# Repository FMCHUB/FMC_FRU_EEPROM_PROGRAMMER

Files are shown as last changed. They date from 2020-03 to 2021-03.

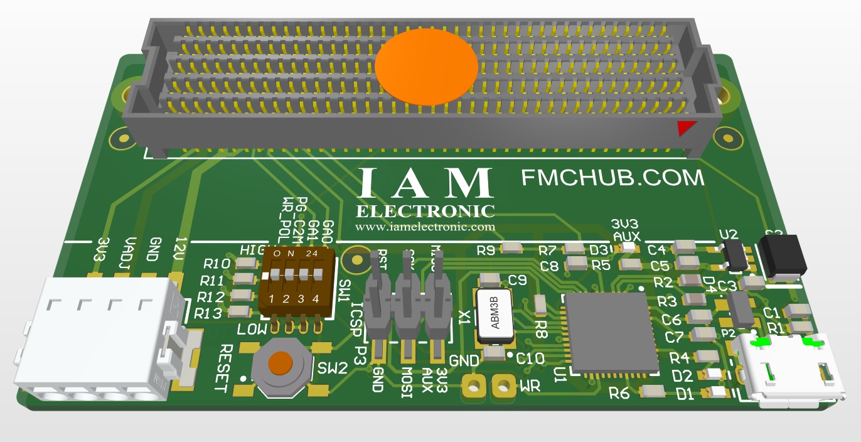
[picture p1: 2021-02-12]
PCB_ALTIUM/3d_pcb_view_revB.jpg

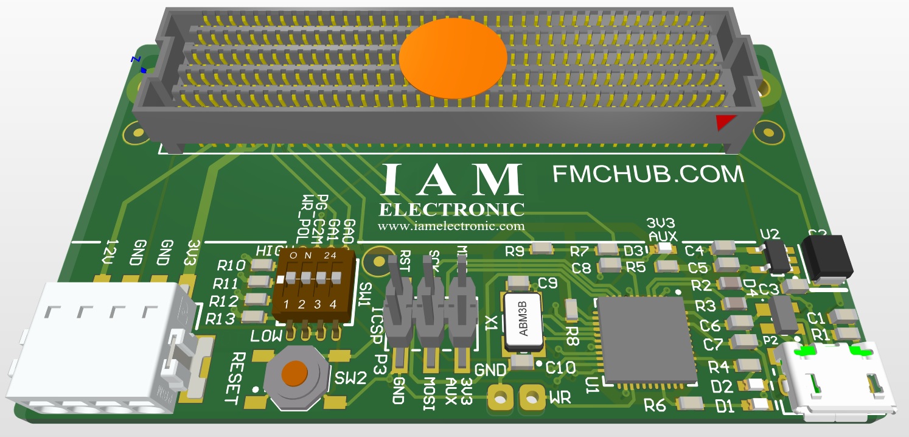
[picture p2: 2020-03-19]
PCB_ALTIUM/3d_pcb_view.jpg

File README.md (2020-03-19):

# FMC_FRU_EEPROM_PROGRAMMER
FRU EEPROM PROGRAMMER FOR FPGA MEZZANINE CARDS (FMC)

1. ./DRIVER

   contains all neccessary driver files for the FMC FRU EEPROM Programmer

2. ./FIRMWARE_ATMEL

   contains the firmware (Atmel Studio project) for the ATMEGA32U4 microcontroller device

3. ./PCB_ALTIUM

   contains the PCB files (Altium designer project) for the FMC FRU EEPROM Programmer

4. ./SOFTWARE_CMD_TOOLS

   contains the command line tools for easy use of FMC FRU EEPROM Programmer

(C) 2020

FMCHUB.COM

IAMELECTRONIC.COM

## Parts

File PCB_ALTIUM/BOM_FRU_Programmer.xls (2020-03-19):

Designator | Description | Manufacturer | Part | Quantity
C1, C3, C4, C7 | CAP 100nF, 0603 (1608 Metric) | KEMET | C0603C104M4RAC7411 | 4
C2 | Standard Tantalum, 22 uF, +/- 10%, 16 V, -55 to 125 degC, 2-Pin SMD (1210), RoHS, Tape and Reel | AVX | TAJB226K016RNJ | 1
C5, C6, C8 | CAP 2.2uF, 0603 (1608 Metric) | KEMET | C0603C225K4PACTU | 3
C9, C10 | CAP 22pF, 0603 (1608 Metric) | Yageo | CC0603JRNPO9BN220 | 2
D1 | LED 0603, 2V, Yellow | Wuerth Elektronik | 150060YS75000 | 1
D2 | LED 0603, 2V, Green | Wuerth Elektronik | 150060VS75000 | 1
D3 | LED 0603, 2V, Red | Wuerth Elektronik | 150060RS75000 | 1
D4 | TVS Diode Array, 30 pF, 30 KV, -40 to 85 degC, 4-Pin SOT143, RoHS, Tape and Reel | Littelfuse | SP0503BAHTG | 1
P1 | CC-LPC-10, FMC Low-pin count connector, lead free, 160 I/Os, female, 10 mm mated stack height | Samtec | ASP-134603-01 | 1
P2 | Micro USB B Type Receptacle, -55 to 85 degC, 5-Pin SMD, RoHS, Tape and Reel | FCI | 10118193-0001LF | 1
P3 | .100" (2.54 mm) pitch 6 pin (dual row) header, 0.38" (9.65 mm) total height, SMT | Samtec | TSM-103-01-T-DV | 1
P4 | Phoenix Contact PTSM SMT connector | Phoenix Contact | 1814650 | 1
R1 | Resistor, 1 MOhm, 0603 (1608 Metric) | Yageo | RC0603JR-071ML | 1
R2, R3 | 22R 0.1W 5% 0603 (1608 Metric) SMD | Yageo | RC0603FR-0722RL | 2
R4, R5, R6 | Resistors, 220 Ohm, +/- 1%, 0603 (1608 Metric) | Yageo | RC0603FR-07220RL | 3
R7, R8, R9, R10, R11, R12, R13 | Resistor, 10 KOhm, 0603 (1608 Metric) | Walsin | WR06X1002FTL | 7
SW1 | 4 channel DIP switch | CTS Electronic Components | 218-4LPST | 1
SW2 | Switch, Tactile, SPST-NO, 50 mA, 12 V, 4-Pin SMD, RoHS, Tape and Reel | E-Switch | TL3342F160QG | 1
U1 | 8-bit AVR Microcontroller, 2.7-5.5V, 16MHz, 32KB Flash, 1KB EEPROM, 2.5KB SRAM, USB Controller, 44-pin QFN, Industrial Grade (-40°C to 85°C), Ext Osc | Microchip | ATMEGA32U4-MU | 1
U2 | Single Output Low Noise LDO, 150 mA, Fixed 3.3 V Output, 1.5% Tolerance, 2.2 to 16 V Input, Low IQ, 5-Pin SOT-23 (DBV), -40 to 125 degC, Green (RoHS & no Sb/Br), Tape and Reel | Texas Instruments | LP2985-33DBVR | 1
X1 | Ceramic Crystal, 8 MHz, +/- 10 ppm, -10 to 60 degC, 4-Pin SMD, RoHS, Tape and Reel | Abracon-LLC | ABM3B-8.000MHZ-10-1-U-T | 1

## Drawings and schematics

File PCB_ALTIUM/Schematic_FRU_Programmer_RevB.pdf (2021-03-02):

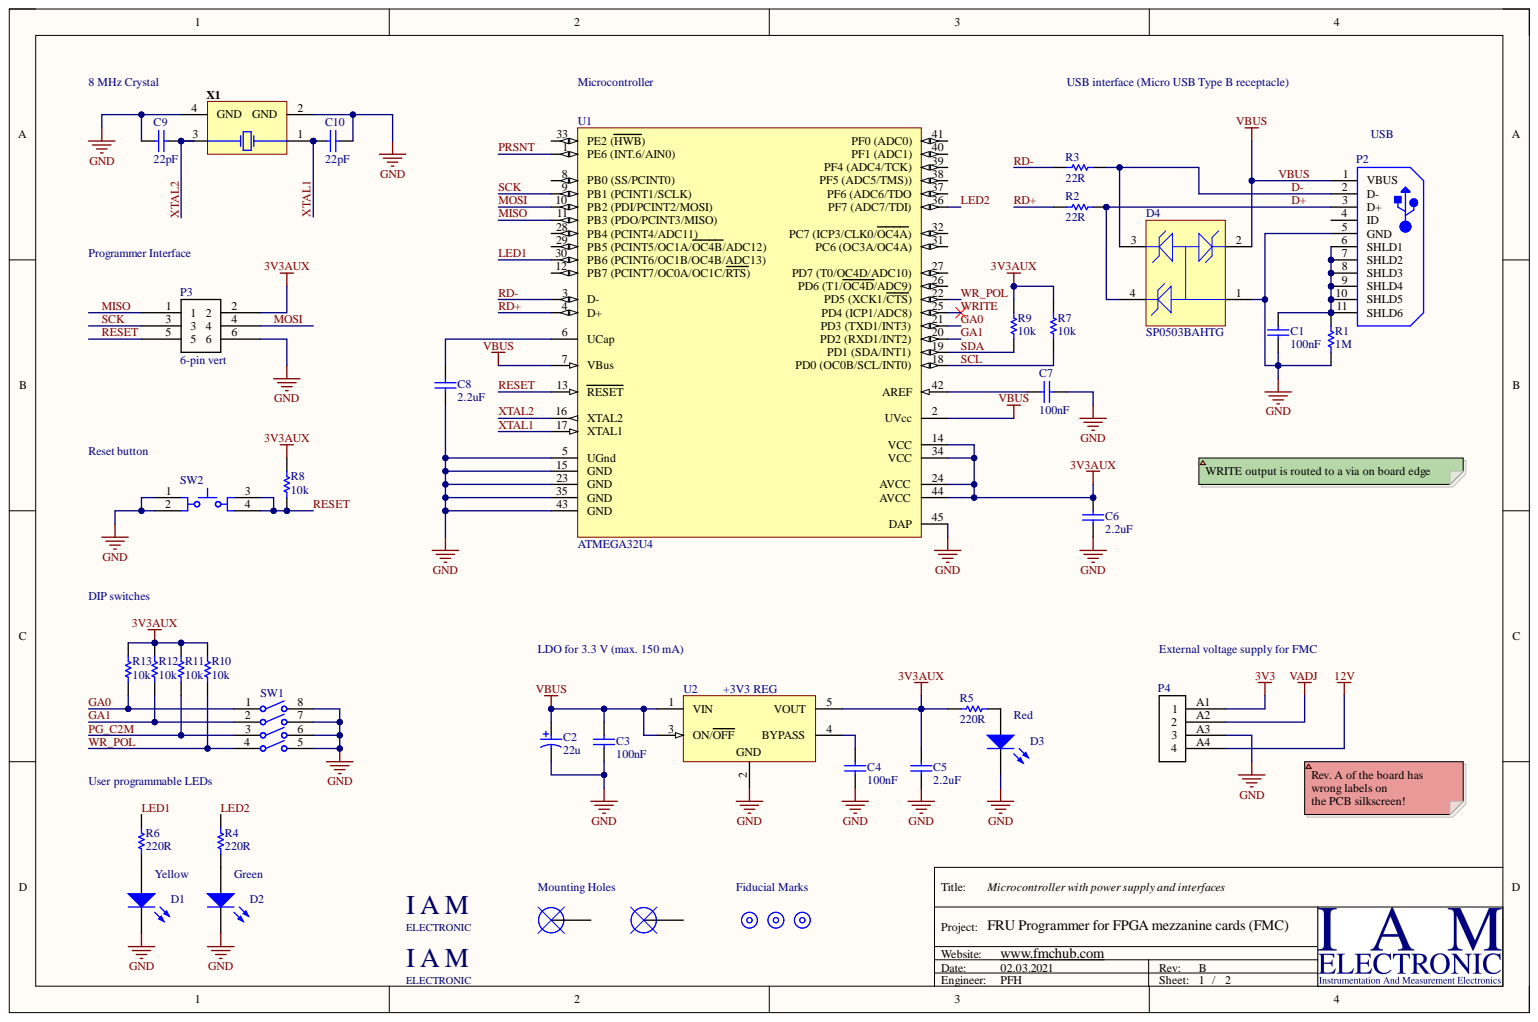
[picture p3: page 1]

USB interface (Micro USB Type B receptacle)

VBUS | VBus 7

SCL

WRITE output is routed to a via on board edge

LDO for 3.3 V (max. 150 mA)

External voltage supply for FMC

Rev. A of the board has
wrong labels on
the PCB silkscreen!

Microcontroller with power supply and interfaces

FRU Programmer for FPGA mezzanine cards (FMC)

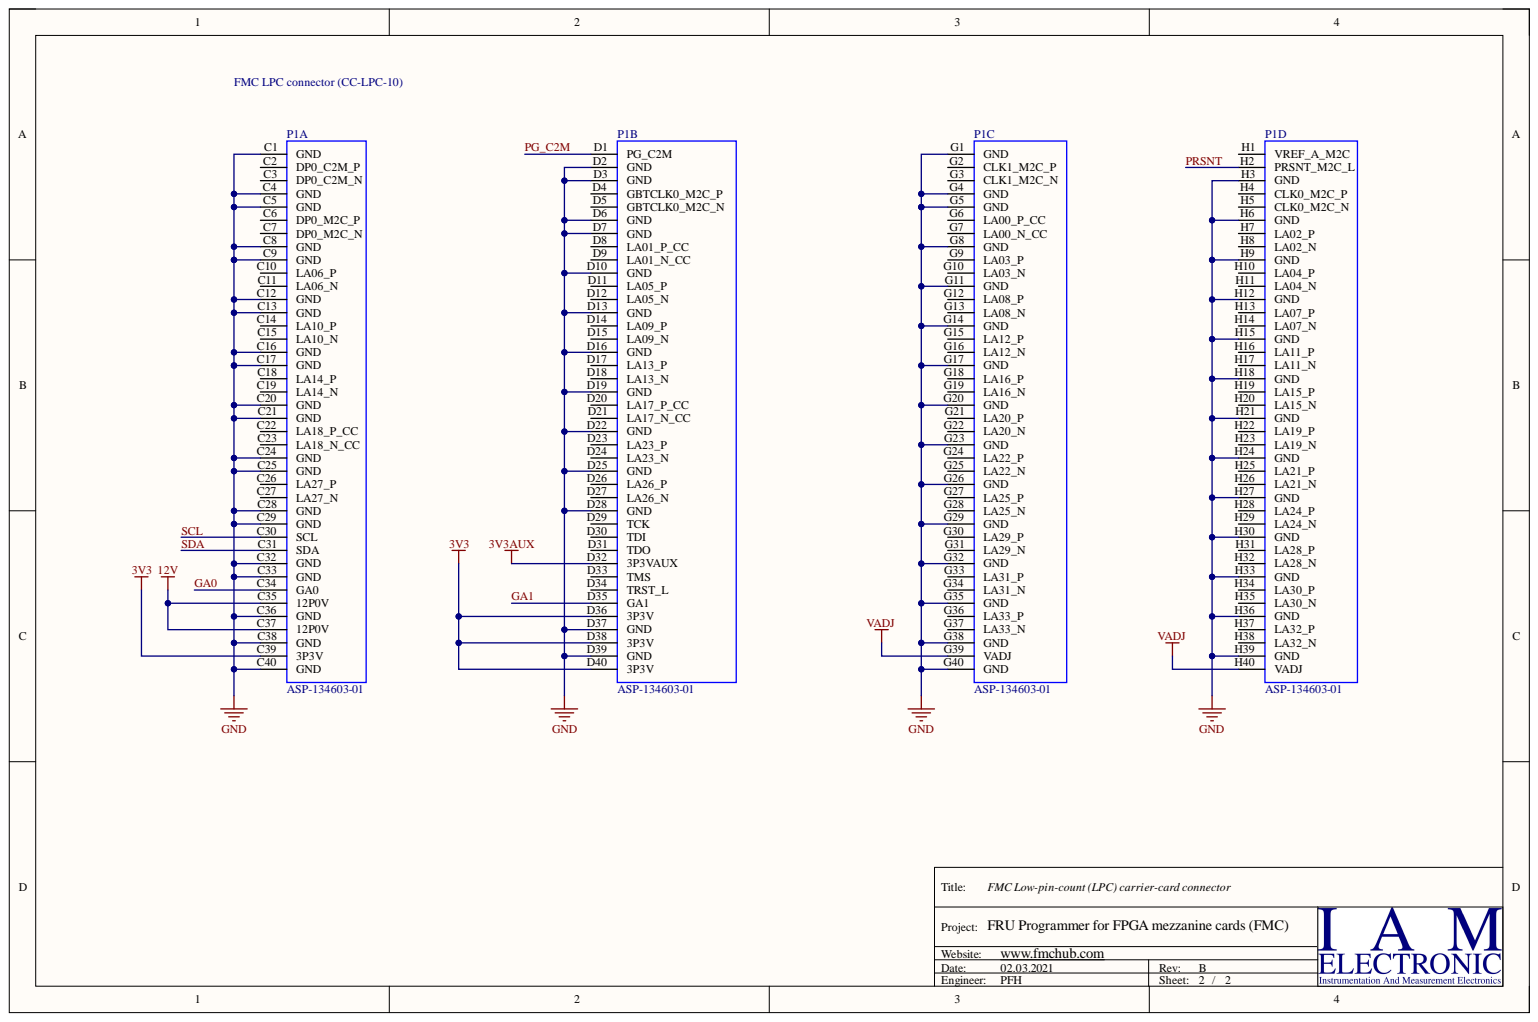
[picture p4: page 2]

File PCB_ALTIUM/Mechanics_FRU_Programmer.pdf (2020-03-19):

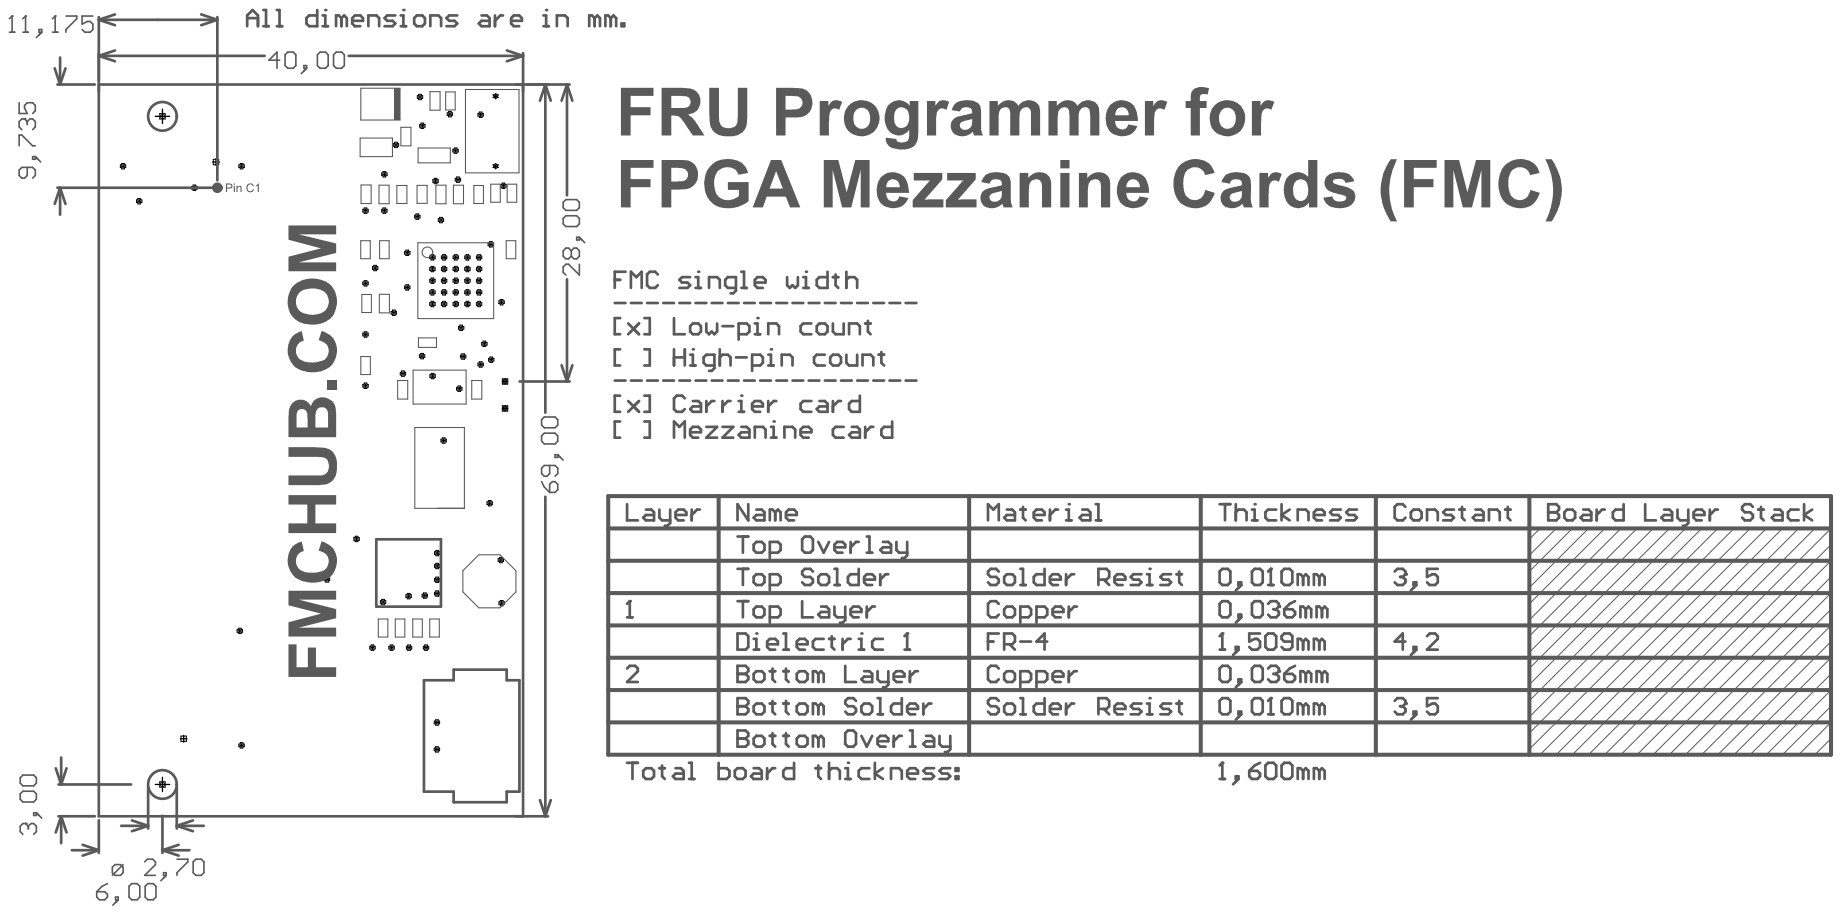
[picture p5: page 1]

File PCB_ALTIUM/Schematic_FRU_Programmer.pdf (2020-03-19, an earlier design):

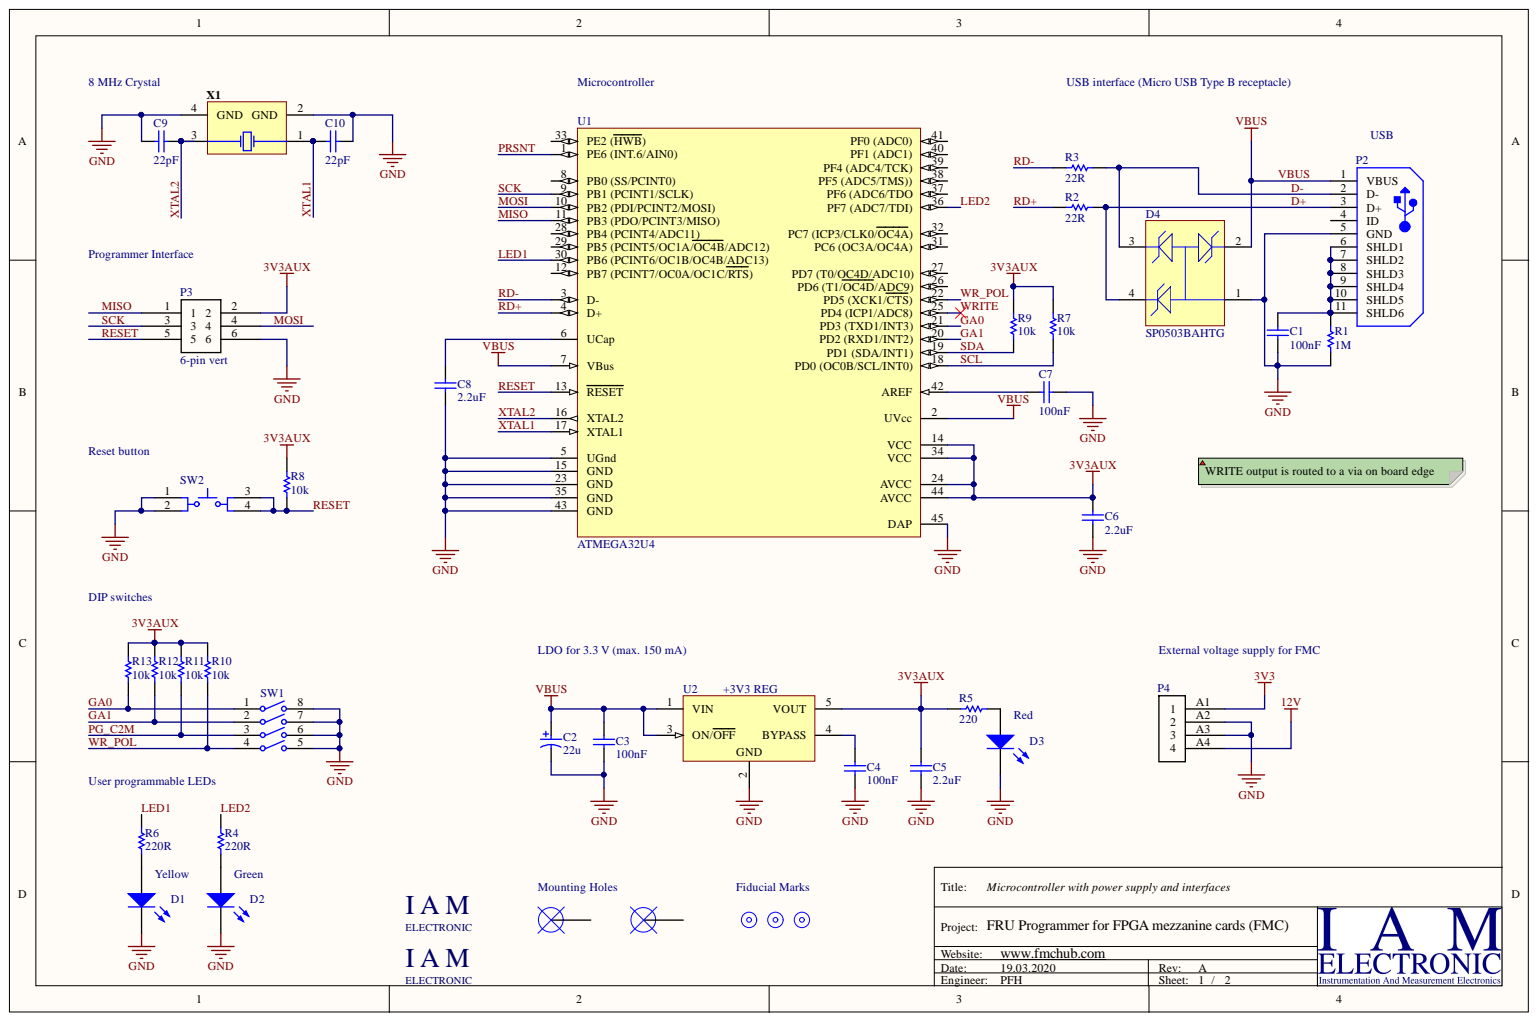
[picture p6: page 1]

USB interface (Micro USB Type B receptacle)

VBUS | VBus 7

SCL

WRITE output is routed to a via on board edge

LDO for 3.3 V (max. 150 mA)

External voltage supply for FMC

Microcontroller with power supply and interfaces

FRU Programmer for FPGA mezzanine cards (FMC)

Date: 19.03.2020 | Rev: A
Engineer: PFH | Sheet: 1 / 2

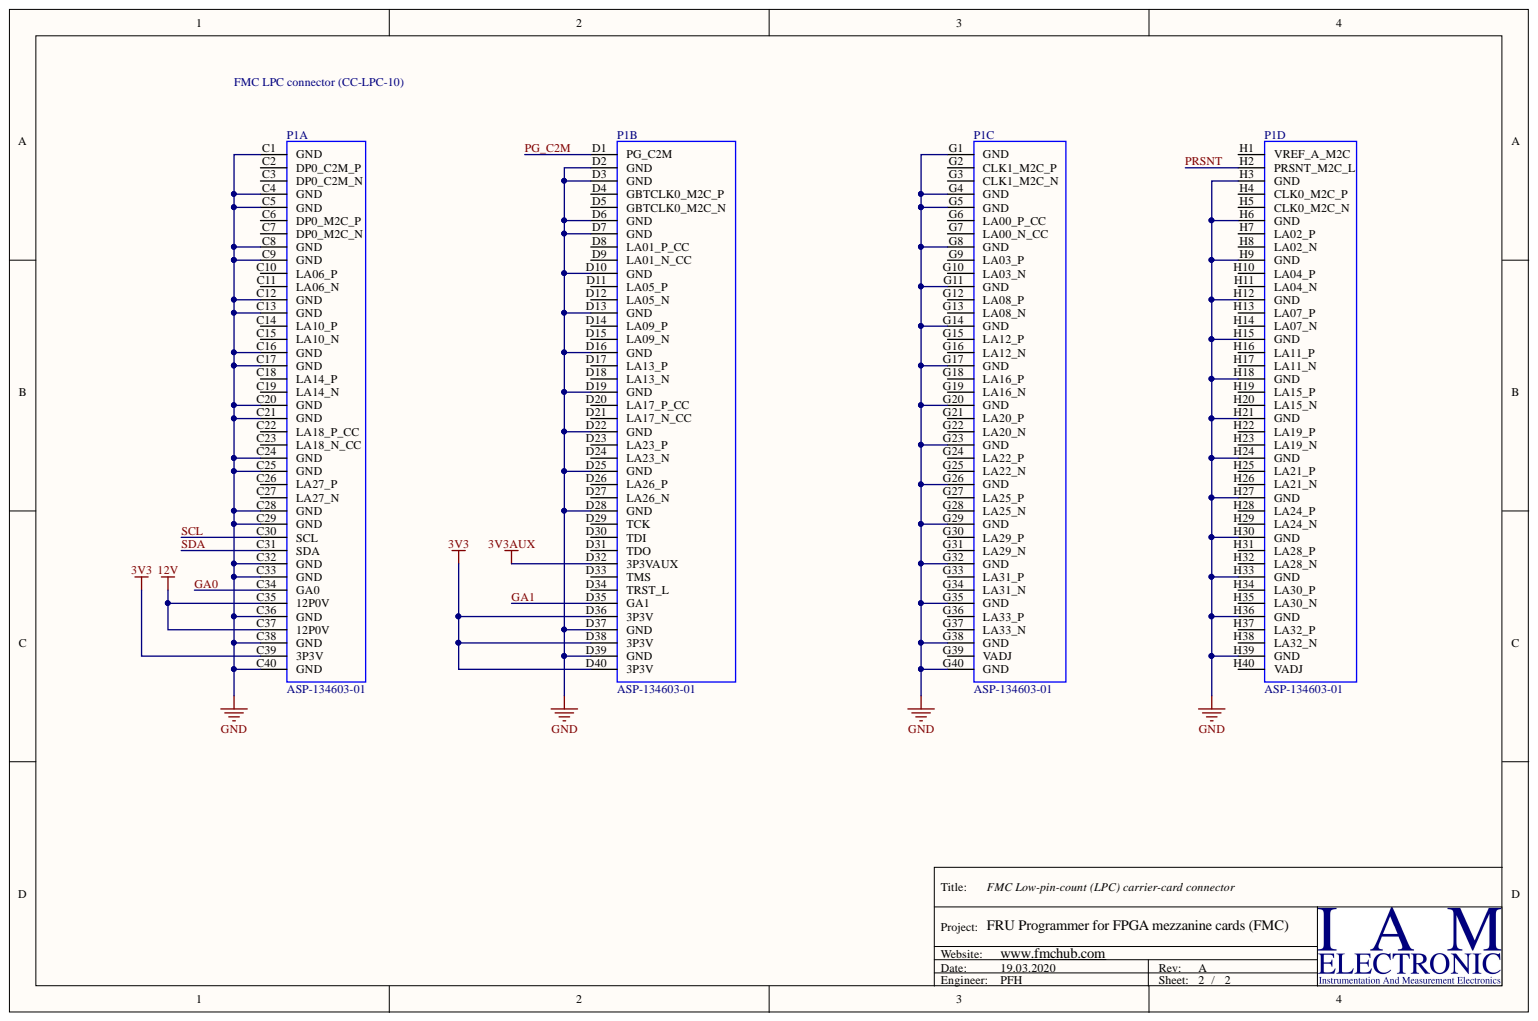
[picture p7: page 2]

Date: 1 9.0 3.2 0 2 0 | Rev : A
E n g i neer: PFH | Sheet : 2 / 2

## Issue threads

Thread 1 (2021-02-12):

12V and 3V3 on Silkscreen is swapped

butchja, 2021-02-12:
On the External FMC power connector the signals are named correctly in the Altium Design. Silkscreen is incorrect. This is potentially damaging the DUT.

FMCHUB, 2021-02-12:
You are right, a stupid mistake. Rev B of the board has been just created.

Closed 2021-02-12.

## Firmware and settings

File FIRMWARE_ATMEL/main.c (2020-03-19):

// Copyright (C) 2020 IAM Electronic GmbH <info@iamelectronic.com>
// This work is free. You can redistribute it and/or modify it under the
// terms of the Do What The Fuck You Want To Public License, Version 2,
// as published by Sam Hocevar. See http://www.wtfpl.net/ for more details.
// ************************************************************************
// File Name	: 'main.c'
// Title		: Main loop for FMC FRU Programmer firmware
// Company		: IAM Electronic GmbH
// Author		: PFH
// Created		: 19-MARCH-2020
// Target HW	: T0009 FMC FRU EEPROM Programmer, ATMEGA32U4
// Target IDE   : Atmel Studio 7 (Version 7.0.2397)
// ************************************************************************

#include "./includes/fru_programmer.h"
#include "./includes/usb_serial.h"
#include "./includes/i2c.h"

#include <avr/pgmspace.h>  // AVR stuff
#include <stdint.h>        // types
#include <util/delay.h>    // delay timer function

void init(void)
{    	
	init_IOports();
	
	set_led(LED_ALL,LED_ON);            // catch some attention, all LEDs on
	
	usb_init();

	while (!usb_configured())
	{
		set_led(LED_YELLOW,LED_TOGGLE); // yellow LED indicates busy state
		_delay_ms(50);
	}
		
	i2c_init();
	
	set_led(LED_ALL,LED_OFF);
}

int main(void)
{
   uint8_t i;                          // default loop variable   
   uint8_t task;                       // task code received from usb uart   
   uint8_t i2c_addr;                   // EEPROM's I2C address
   uint8_t bytes_to_read;              // number of bytes to read with a I2C read burst
   uint8_t bytes_to_write;             // number of bytes to write with a I2C write burst
   uint8_t fru_addr_msb;               // EEPROM target address for read/write access
   uint8_t fru_addr_lsb;               // EEPROM target address for read/write access, LSB is not used in case of 1 byte addressing
   uint8_t fru_data;                   // EEPROM target data
   uint8_t i2c_buf[I2C_BUFFERSIZE];    // buffer for I2C bus data
   
   init();                             // initializes hardware 
       
   usb_serial_flush_input();           // discard anything that was received prior
   
   bytes_to_read  = I2C_DEFAULT_READ;  // default value supported by all EEPROMs
   bytes_to_write = I2C_DEFAULT_WRITE; // default value supported by all EEPROMs
   
   while (1)                           // main loop
   {	
	  
	  // GREEN LED SHOULD BE TURNED ON WHEN FMC MODULE IS PLUGGED IN
      if (get_prsnt_state()==INPUT_LOW)
         set_led(LED_GREEN,LED_ON);                                  // FMC Module is plugged in
      else
         set_led(LED_GREEN,LED_OFF);                                 // FMC Module is not plugged in
	
      // SET WRITE PIN, STATE DEPENDS ON WR_POL PIN (DIP SWITCH SW1)
      if (get_wrpol_state()==INPUT_LOW)                              // 0 = active low write enable (WR pin will be low during write cycles, high in idle)
         set_writepin(WR_ON);                                        // enable write protection (write enable is active low, idle is high)
      else
		 set_writepin(WR_OFF);                                       // enable write protection (write enable is active high, idle is low)
		 
	  // READ NEW TASK FROM USB UART
      if (usb_serial_available()>0)                                  // valid data is in rx buffer
      {
         set_led(LED_YELLOW,LED_ON);                                 // indicate busy state
         task = usb_serial_getchar();                                // get first byte from buffer, that code determines next task
         switch(task)                                                // decode task
         {
			case 'b': // 0x62 b = bytes to read in a burst
			          if (usb_serial_available()==1)                 // command has one argument
			          {  
				         i = usb_serial_getchar();                   // get next byte from recv buffer
						 if ((i>=1) && (i<=I2C_MAX_READ))
						 {
                            bytes_to_read = i;
						    usb_serial_putchar(UART_ACK);            // send ACK
							usb_serial_putchar(bytes_to_read);       // send current value	 
						 }
						 else
						 {
                            bytes_to_read = I2C_DEFAULT_READ;        // restore defaults
							usb_serial_putchar(UART_NACK);           // wrong range of parameter
						 }
			          }
					  else if (usb_serial_available()==0)            // command has one argument
					  {
						  usb_serial_putchar(bytes_to_read);         // print current settings
					  }
			          else
			          {
				         usb_serial_putchar(UART_NACK);              // not enough data, end of transmission
			          }
			          break;
					  			 
            case 'f': // 0x66 f = printf 0xff
			          usb_serial_putchar(0xFF);
                      break;
					  
            case 'g': // 0x67 g = global address (GA) pins of dip switch SW1
			          i2c_addr = get_GA_state();                     // read GA1 and GA0 pins 
                      usb_serial_putchar(i2c_addr);                  // print values
                      break;
					  
            case 'p': // 0x70 p = presence of the FMC module
                      if (get_prsnt_state()==INPUT_LOW)
                         usb_serial_putchar(0x01);                   // FMC Module is attached, send 0x01
                      else
                         usb_serial_putchar(0x00);                   // FMC Module is not attached, send 0x00
                      break;
					  
            case 'P': // 0x50 P = Protection polarity (possible write protect polarity of EEPROM)
                      if (get_wrpol_state()==INPUT_LOW)
                         usb_serial_putchar(0x00);                   // WR_POL is low (dip switch SW1)
                      else
                         usb_serial_putchar(0x01);                   // WR_POL is high (dip switch SW1)                      
                      break;
					  								  					  
            case 'r': // 0x72 r = read with 1 byte addressing
			          if (usb_serial_available()==2)                 // command has two arguments
			          {
				          usb_serial_putchar(UART_ACK);              // send ACK
						  i2c_addr     = usb_serial_getchar();       // get next byte from recv buffer
				          fru_addr_msb = usb_serial_getchar();       // get next byte from recv buffer
						  i2c_buf[0]   = fru_addr_msb;               // generate I2C data buffer
						  set_writepin(WR_TOGGLE);                               // mask read access with WR pin
						  i2c_write(i2c_addr, (uint8_t*)i2c_buf, 1);             // transmit adddr to read				  
						  i2c_read(i2c_addr,  (uint8_t*)i2c_buf, bytes_to_read); // read data into same buffer
						  set_writepin(WR_TOGGLE);                               // unmask read access with WR pin
						  for (i=0;i<bytes_to_read;i++)
						     usb_serial_putchar(i2c_buf[i]);                     // send I2C readoutdata
			          }
			          else
			          {
				          usb_serial_putchar(UART_NACK);             // not enough data, end of transmission
			          }
                      break;
					  
            case 'R': // 0x52 R = Read with 2 byte addressing
			          if (usb_serial_available()==3)                 // command has three arguments
			          {
				          usb_serial_putchar(UART_ACK);              // send ACK
				          i2c_addr     = usb_serial_getchar();       // get next byte from recv buffer
				          fru_addr_msb = usb_serial_getchar();       // get next byte from recv buffer
				          fru_addr_lsb = usb_serial_getchar();       // get next byte from recv buffer
						  i2c_buf[0]   = fru_addr_msb;               // generate I2C data buffer
						  i2c_buf[1]   = fru_addr_lsb;               // generate I2C data buffer
						  set_writepin(WR_TOGGLE);                               // mask read access with WR pin
						  i2c_write(i2c_addr, (uint8_t*)i2c_buf, 2);             // transmit addr to read						  
						  i2c_read(i2c_addr,  (uint8_t*)i2c_buf, bytes_to_read); // read data into same buffer
						  set_writepin(WR_TOGGLE);                               // unmask read access with WR pin
						  for (i=0;i<bytes_to_read;i++)
						     usb_serial_putchar(i2c_buf[i]);                     // send I2C readoutdata
			          }
			          else
			          {
				          usb_serial_putchar(UART_NACK);             // not enough data, end of transmission
			          }
                      break;
					  								  
            case 's': // 0x73 s = scan for EEPROM addresses
				      for (i = 0; i < 8; i++)
				      {
					     i2c_addr = I2C_EEPROM_ADDR_7BIT | i;        // scan on fixed EEPROM address and increment lowest 3 bits
					     if(i2c_scan(i2c_addr) == 1)                
					        usb_serial_putchar(i2c_addr);            // print valid I2C address
				      }
				      usb_serial_putchar(UART_END);                  // end of transmission
                      break;
					  
            case 'v': // 0x76 v = version of firmware
					  usb_serial_putchar(FRU_PROGRAMMER_FW_REL_MAJ);
					  usb_serial_putchar(FRU_PROGRAMMER_FW_REL_MIN);
					  usb_serial_putchar(FRU_PROGRAMMER_FW_BUILD);
					  usb_serial_putchar(UART_END);                  // end of transmission
                      break;
					  
            case 'w': // 0x77 w = write with 1 byte addressing
			          if (usb_serial_available()>=3)                 // command has at least three arguments
			          {
						  bytes_to_write = usb_serial_available() - 2; // get number of bytes in commando string (offset 2: 1 byte I2C addr, 1 byte mem addr)
				          usb_serial_putchar(UART_ACK);                // send ACK
				          i2c_addr     = usb_serial_getchar();         // get next byte from recv buffer
				          fru_addr_msb = usb_serial_getchar();         // get next byte from recv buffer				          				  
						  i2c_buf[0]   = fru_addr_msb;                 // generate I2C data buffer
						  for (i=0;i<bytes_to_write;i++)
						  {
							  fru_data     = usb_serial_getchar();     // get next byte from recv buffer		
							  i2c_buf[1+i] = fru_data;                 // generate I2C data buffer
						  }
						  set_writepin(WR_TOGGLE);                                  // toggle WR pin
						  i2c_write(i2c_addr, (uint8_t*)i2c_buf, 1+bytes_to_write); // transmit data and write to EEPROM
						  set_writepin(WR_TOGGLE);                                  // toggle WR pin
			          }
			          else
			          {
				          usb_serial_putchar(UART_NACK);             // not enough data, end of transmission
			          }
                      break;
					  
            case 'W': // 0x57 w = write with 2 byte addressing
			          if (usb_serial_available()>=4)                 // command has at least four arguments
					  {
						 bytes_to_write = usb_serial_available() - 3; // get number of bytes in commando string (offset 3: 1 byte I2C addr, 2 byte mem addr)
                         usb_serial_putchar(UART_ACK);                // send ACK
			             i2c_addr     = usb_serial_getchar();         // get next byte from recv buffer
			             fru_addr_msb = usb_serial_getchar();         // get next byte from recv buffer
					     fru_addr_lsb = usb_serial_getchar();         // get next byte from recv buffer			             
						 i2c_buf[0]   = fru_addr_msb;                 // generate I2C data buffer
						 i2c_buf[1]   = fru_addr_lsb;                 // generate I2C data buffer
						 for (i=0;i<bytes_to_write;i++)
						 {
							 fru_data     = usb_serial_getchar();     // get next byte from recv buffer
							 i2c_buf[2+i] = fru_data;                 // generate I2C data buffer
						 }						 
						 set_writepin(WR_TOGGLE);                                   // toggle WR pin
						 i2c_write(i2c_addr, (uint8_t*)i2c_buf, 2+bytes_to_write);  // transmit data and write to EEPROM
						 set_writepin(WR_TOGGLE);                                   // toggle WR pin
					  }
					  else
					  {
                         usb_serial_putchar(UART_NACK);              // not enough data, end of transmission
					  }
                      break;					  
         } // end switch
         usb_serial_flush_input();
         set_led(LED_YELLOW,LED_OFF);
      } // end if
   } // end while(1) main loop
}

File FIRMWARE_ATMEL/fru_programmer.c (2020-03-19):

// Copyright © 2020 IAM Electronic GmbH <info@iamelectronic.com>
// This work is free. You can redistribute it and/or modify it under the
// terms of the Do What The Fuck You Want To Public License, Version 2,
// as published by Sam Hocevar. See http://www.wtfpl.net/ for more details.
// ************************************************************************
// File Name	: 'fru_programmer.c'
// Title		: Low level hardware functions
// Company		: IAM Electronic GmbH
// Author		: PFH
// Created		: 19-MARCH-2020
// Target HW	: T0009 FMC FRU EEPROM Programmer, ATMEGA32U4
// Target IDE   : Atmel Studio 7 (Version 7.0.2397)
// ************************************************************************

#include "./includes/fru_programmer.h"

/*
 * initializes all data direction registers
 */
void init_IOports(void)
{
   /*
   * HARDWARE PORTS ON FRU PROGRAMMER   
   * LED1 (green) : output port PB6
   * LED2 (yellow): output port PF6
   * WRITE        : output port PD4 (WR pin on FRU programmer)
   * 
   * PRSNT        : input  port PE6 (present pin from FMC module)
   * WR_POL       : input  port PD5 (dip switch SW1 on FRU programmer)
   * GA0          : input  port PD3 (dip switch SW1 on FRU programmer)
   * GA1          : input  port PD2 (dip switch SW1 on FRU programmer)
   */
   DDRB |=  (1 << PB6);  // LED1 (Yellow)
   DDRF |=  (1 << PF7);  // LED2 (Green)
   DDRD |=  (1 << PD4);  // WRITE

   DDRE  &= ~(1 << PE6);  // PRSNT
   PORTE |=  (1 << PE6);  // Use internal Pull-UP
		
   DDRD  &= ~(1 << PD5);  // WR_POL
   PORTD &= ~(1 << PD5);  // Tri-State, has external Pull-Up
   
   DDRD  &= ~(1 << PD3);  // GA0
   PORTD &= ~(1 << PD3);  // Tri-State, has external Pull-Up
   
   DDRD  &= ~(1 << PD2);  // GA1
   PORTD &= ~(1 << PD2);  // Tri-State, has external Pull-Up
}

/*
 * Changes state of LED
 */
void set_led(uint8_t led_idx, uint8_t state)
{	
	switch(state)
	{
		case LED_TOGGLE: if (led_idx==LED_ALL || led_idx==LED_YELLOW)
                            PORTB ^= (1 << PB6);
				         if (led_idx==LED_ALL || led_idx==LED_GREEN)
                            PORTF ^= (1 << PF7);
				         break;				 
		case  LED_OFF:   if (led_idx==LED_ALL || led_idx==LED_YELLOW)
		                    PORTB &= ~(1 << PB6);
				         if (led_idx==LED_ALL || led_idx==LED_GREEN)	
                            PORTF &= ~(1 << PF7);
		                 break;
		case  LED_ON:    if (led_idx==LED_ALL || led_idx==LED_YELLOW)
		                    PORTB |= (1 << PB6);
				         if (led_idx==LED_ALL || led_idx==LED_GREEN)	
					        PORTF |= (1 << PF7);
		                 break;
	}
}

/*
 * Changes state of WR pin
 */
void set_writepin(uint8_t state)
{	
	switch(state)
	{
		case WR_TOGGLE: PORTD ^=  (1 << PD4);
				        break;				 
		case WR_OFF:    PORTD &= ~(1 << PD4);
                        break;
		case WR_ON:     PORTD |=  (1 << PD4);
		                break;
	}
}

/*
 * Read PRSNT flag from FMC connector
 * returns 0 if FMC module is connected (PRSNT pin has GND potential = logical 0)
 * returns 1 if FMC module is not connected (PRSNT pin is floating)
 */
uint8_t get_prsnt_state(void)
{	
   if(PINE & (1 << PE6))
      return INPUT_HIGH;
   else
      return INPUT_LOW;
}

/*
 * Read WR_POL logical state from SW1
 * 0 = active low  write protect (WR pin is high during write cycles)
 * 1 = active high write protect (WR pin is low during write cycles)
 */
uint8_t get_wrpol_state(void)
{	
   if(PIND & (1 << PD5))
      return INPUT_HIGH;
   else
      return INPUT_LOW;
}

/*
 * Read GA1 and GA0 logical state from SW1
 */
uint8_t get_GA_state(void)
{
   uint8_t GA0 = 0x00;
   uint8_t GA1 = 0x00;
   uint8_t ret = 0x00;
   if(PIND & (1 << PD3))
      GA0 = 0x01;
   if(PIND & (1 << PD2))
	  GA1 = 0x01;
   ret |= (GA1 << 1);
   ret |= (GA0 << 0);
   return ret;
}

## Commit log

2021-02-12 fix: wrong labels on silkscreen add: access to VADJ on connector P4 (replaced GND with VADJ port)
    [FRU_Programmer.SchDoc, FRU_Programmer_LPC.SchDoc]
2021-02-12 edit: set new origin in PCB and redraw GND planes
    [FRU_Programmer.PrjPcb]
2021-03-02 edit: fixed some comments of parts in schematics, new origin for pick and place file generation
    [FRU_Programmer.PrjPcb, FRU_Programmer.SchDoc, FRU_Programmer_LPC.SchDoc]
